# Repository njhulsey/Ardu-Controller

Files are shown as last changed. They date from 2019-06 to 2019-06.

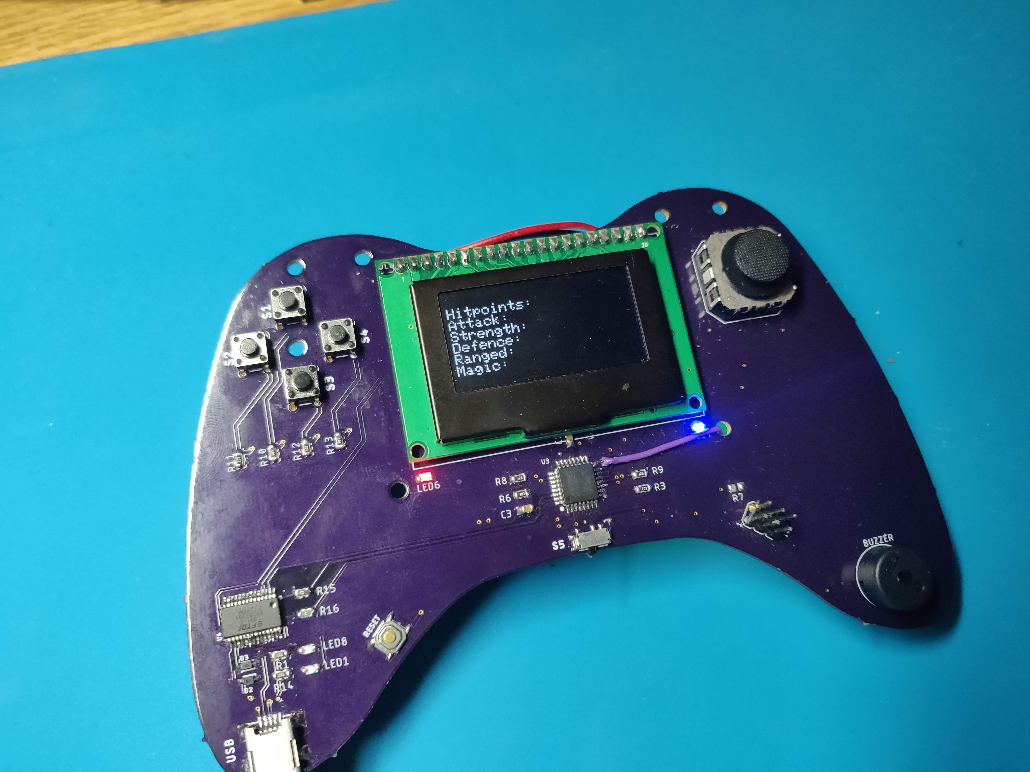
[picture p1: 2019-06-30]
Photo.jpg

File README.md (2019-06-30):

# Ardu-Controller
Arduino inspired hand-held controller!

Contains all of the basic circuitry for an arduino Uno as well as some addition devices:
  - Adafruit OLED
  - Joystick
  - 4 Dip Buttons
  - Buzzer
  - lipo battery charger
  - LEDs
  - Serial (which is used to communicate with a PC)
  
As for the code there are two projects included in this repository. 
The first project is used for controlling a mouse with the game controller using python's serial class.
The second project is snake which can be played on the controller itself.

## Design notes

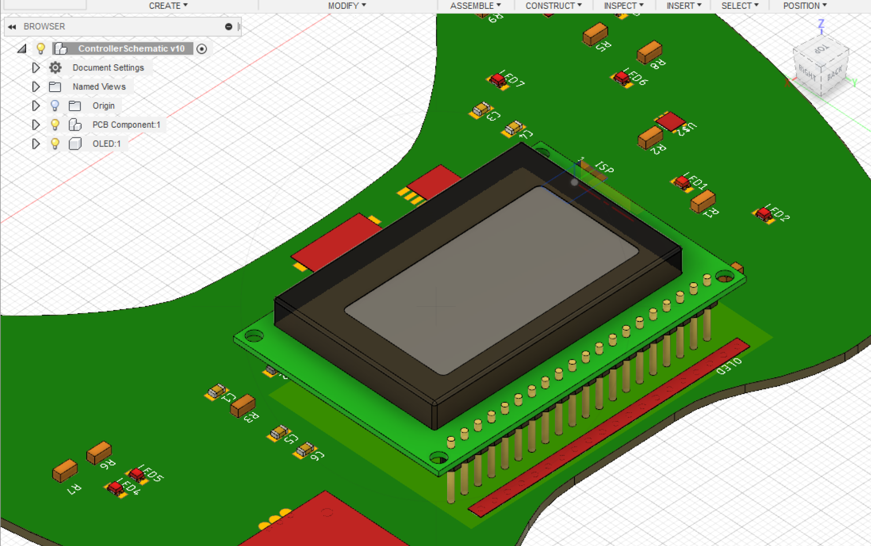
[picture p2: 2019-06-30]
EagleFiles/MechanicalFiles/Sketch.png

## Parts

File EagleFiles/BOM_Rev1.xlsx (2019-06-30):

Part Number | Manufacturer | Description | Reference | Price | Quantity | Link
2765 | Adafruit | Mini 2-Axis Analog Thumbstick |  | $2.50 | 1 | https://www.adafruit.com/product/2765
2720 | Adafruit | Monochrome 1.54" OLED |  | $34.95 | 1 | https://www.adafruit.com/product/2720
97 | Sparkfun | Mini Pushbutton Switch 6mm |  | $0.35 | 1 | https://www.sparkfun.com/products/97
UX60-MB-5ST | Hirose | USB Connector Mini B |  | $0.90 | 1 | https://www.mouser.com/ProductDetail/Hirose-Connector/UX60-MB-5ST
768-1007-1-ND | FTDI | IC USB FS SERIAL UART 28-SSOP |  | $4.50 | 1 | https://www.digikey.com/products/en?keywords=768-1007-1-ND
10860 | Sparkfun | Surface Mount Right Angle Switch |  | $0.95 | 1 | https://www.sparkfun.com/products/10860
1016-1873-1-ND | MaxLinear | IC REG LINEAR 3.3V 500MA SOT23-5 |  | $0.60 | 1 | https://www.digikey.com/product-detail/en/maxlinear-inc/SPX3819M5-L-3-3-TR/1016-1873-1-ND/3586590
MBR120VLSFT3GOSCT | ON Semiconductor | DIODE SCHOTTKY 20V 1A SOD123FL |  | $0.42 | 1 | https://www.digikey.com/product-detail/en/on-semiconductor/MBR120VLSFT3G/MBR120VLSFT3GOSCT-ND/3487322
CDSOD323-T08L | Bourns | ESD 8.5V 1PF SOD323 DIODE |  | $0.76 | 2 | https://www.mouser.com/ProductDetail/Bourns/CDSOD323-T08L
MCP73831T-2ACI/OTCT-ND | Microchip | IC CONTROLLR LI-ION 4.2V SOT23-5 |  | $0.58 | 1 | https://www.digikey.com/product-detail/en/microchip-technology/MCP73831T-2ACI-OT/MCP73831T-2ACI-OTCT-ND/1979802
2011 | Adafruit | LIPO ION BATT - 3.7V 2000mAh |  | $12.50 | 1 | https://www.adafruit.com/product/2011
ATMEGA328P-AU-ND | Microchip | ATMEGA328P 8BIT 32KB FLASH 32TQFP |  | $2.07 | 1 | https://www.digikey.com/product-detail/en/microchip-technology/ATMEGA328P-AU/ATMEGA328P-AU-ND/1832260

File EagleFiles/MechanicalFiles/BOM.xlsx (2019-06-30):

Name | Part Number | ID | Amount | Cost | Link
Atmega328P-PU |  |  |  |  | https://www.digikey.com/product-detail/en/microchip-technology/ATMEGA328P-AU/ATMEGA328P-AU-ND/1832260
Micro USB Connector |  |  |  |  | https://www.alliedelec.com/product/molex-incorporated/54819-0519/70090672/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

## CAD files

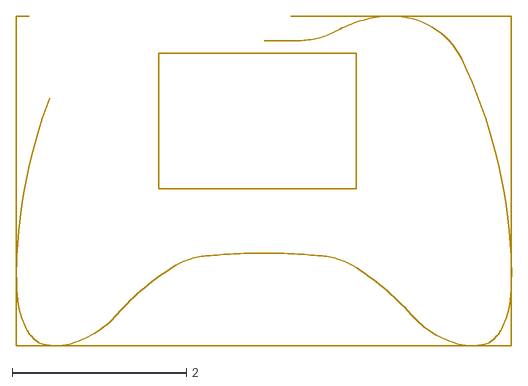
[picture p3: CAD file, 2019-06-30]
EagleFiles/MechanicalFiles/contollerEXPORT.dxf
5.69 x 3.79

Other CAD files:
EagleFiles/MechanicalFiles/ControllerOutline.dwg

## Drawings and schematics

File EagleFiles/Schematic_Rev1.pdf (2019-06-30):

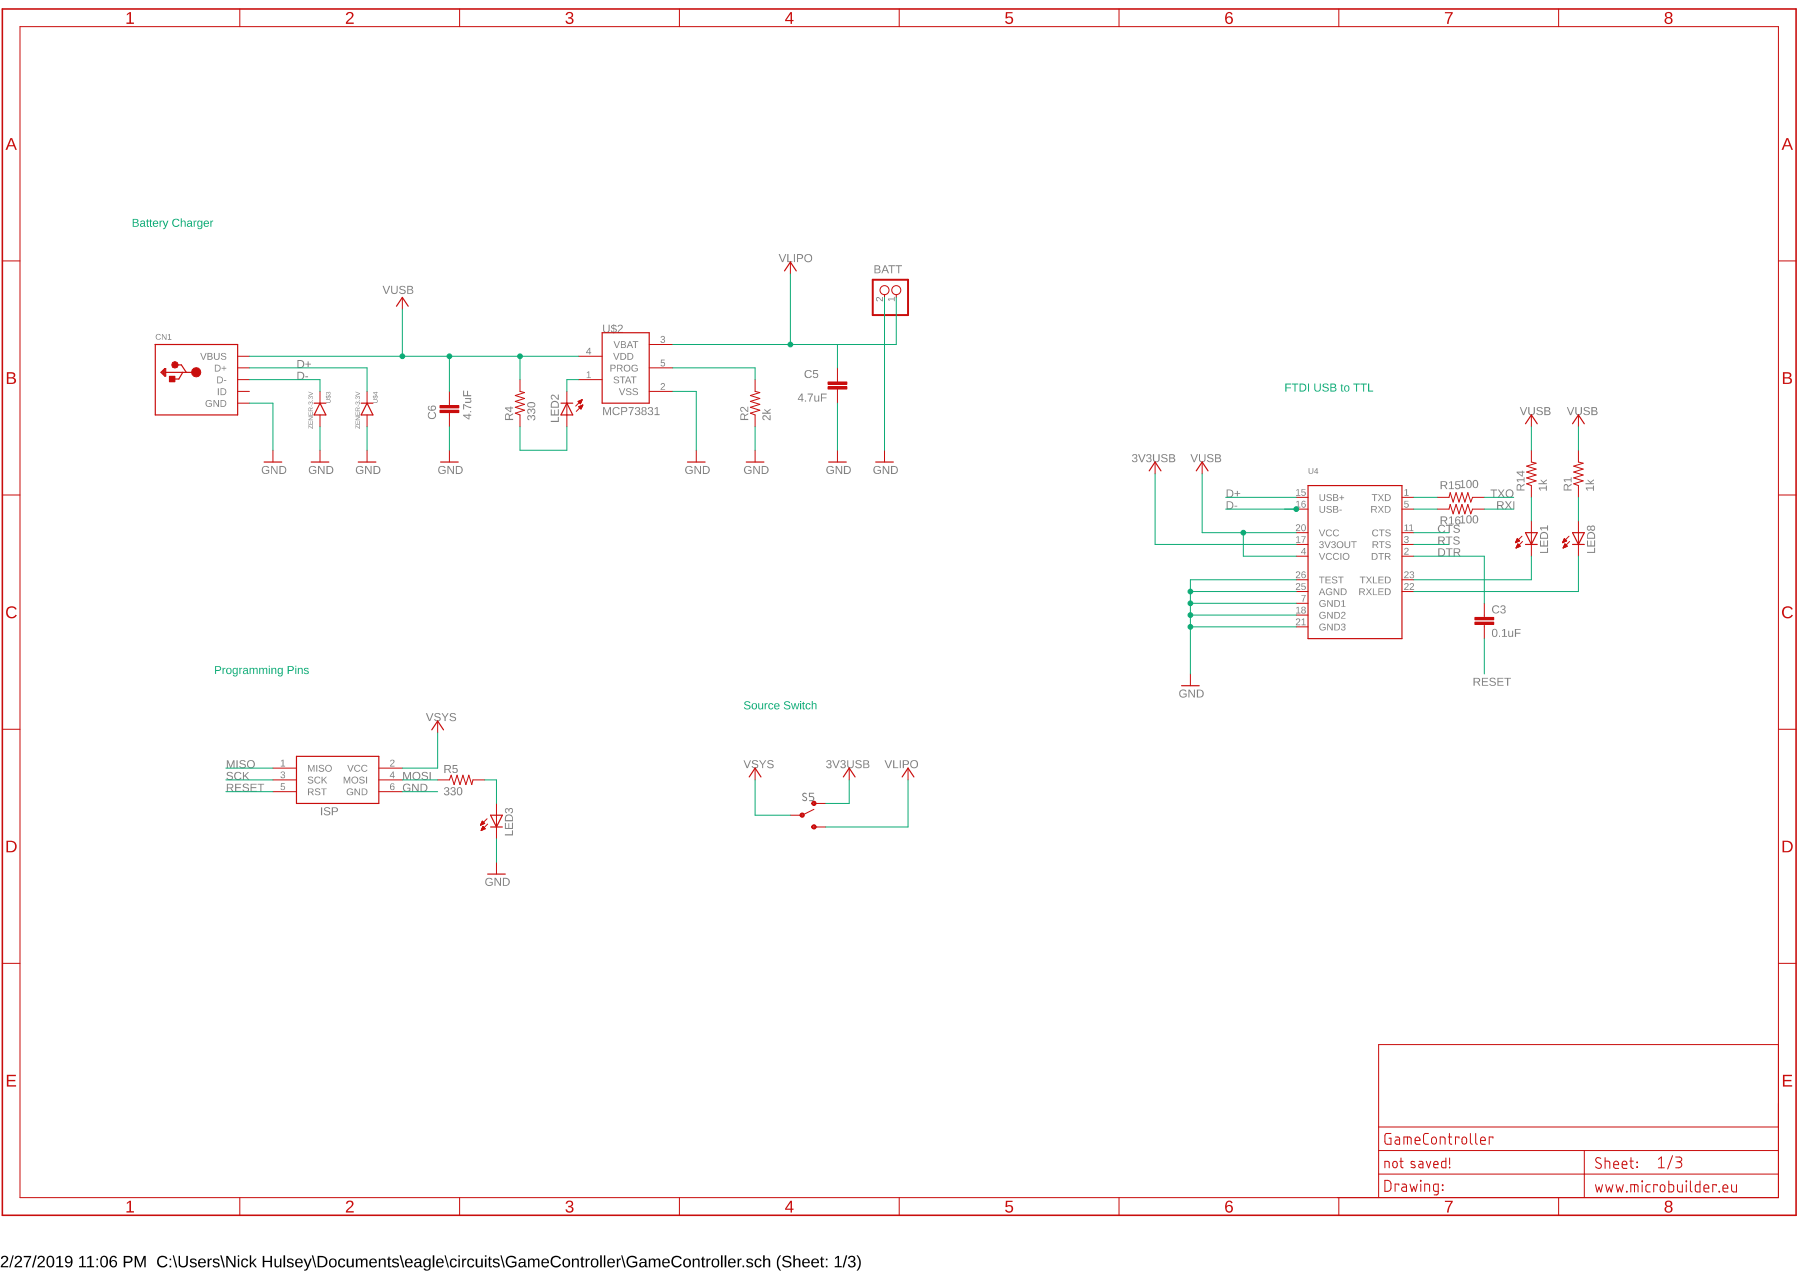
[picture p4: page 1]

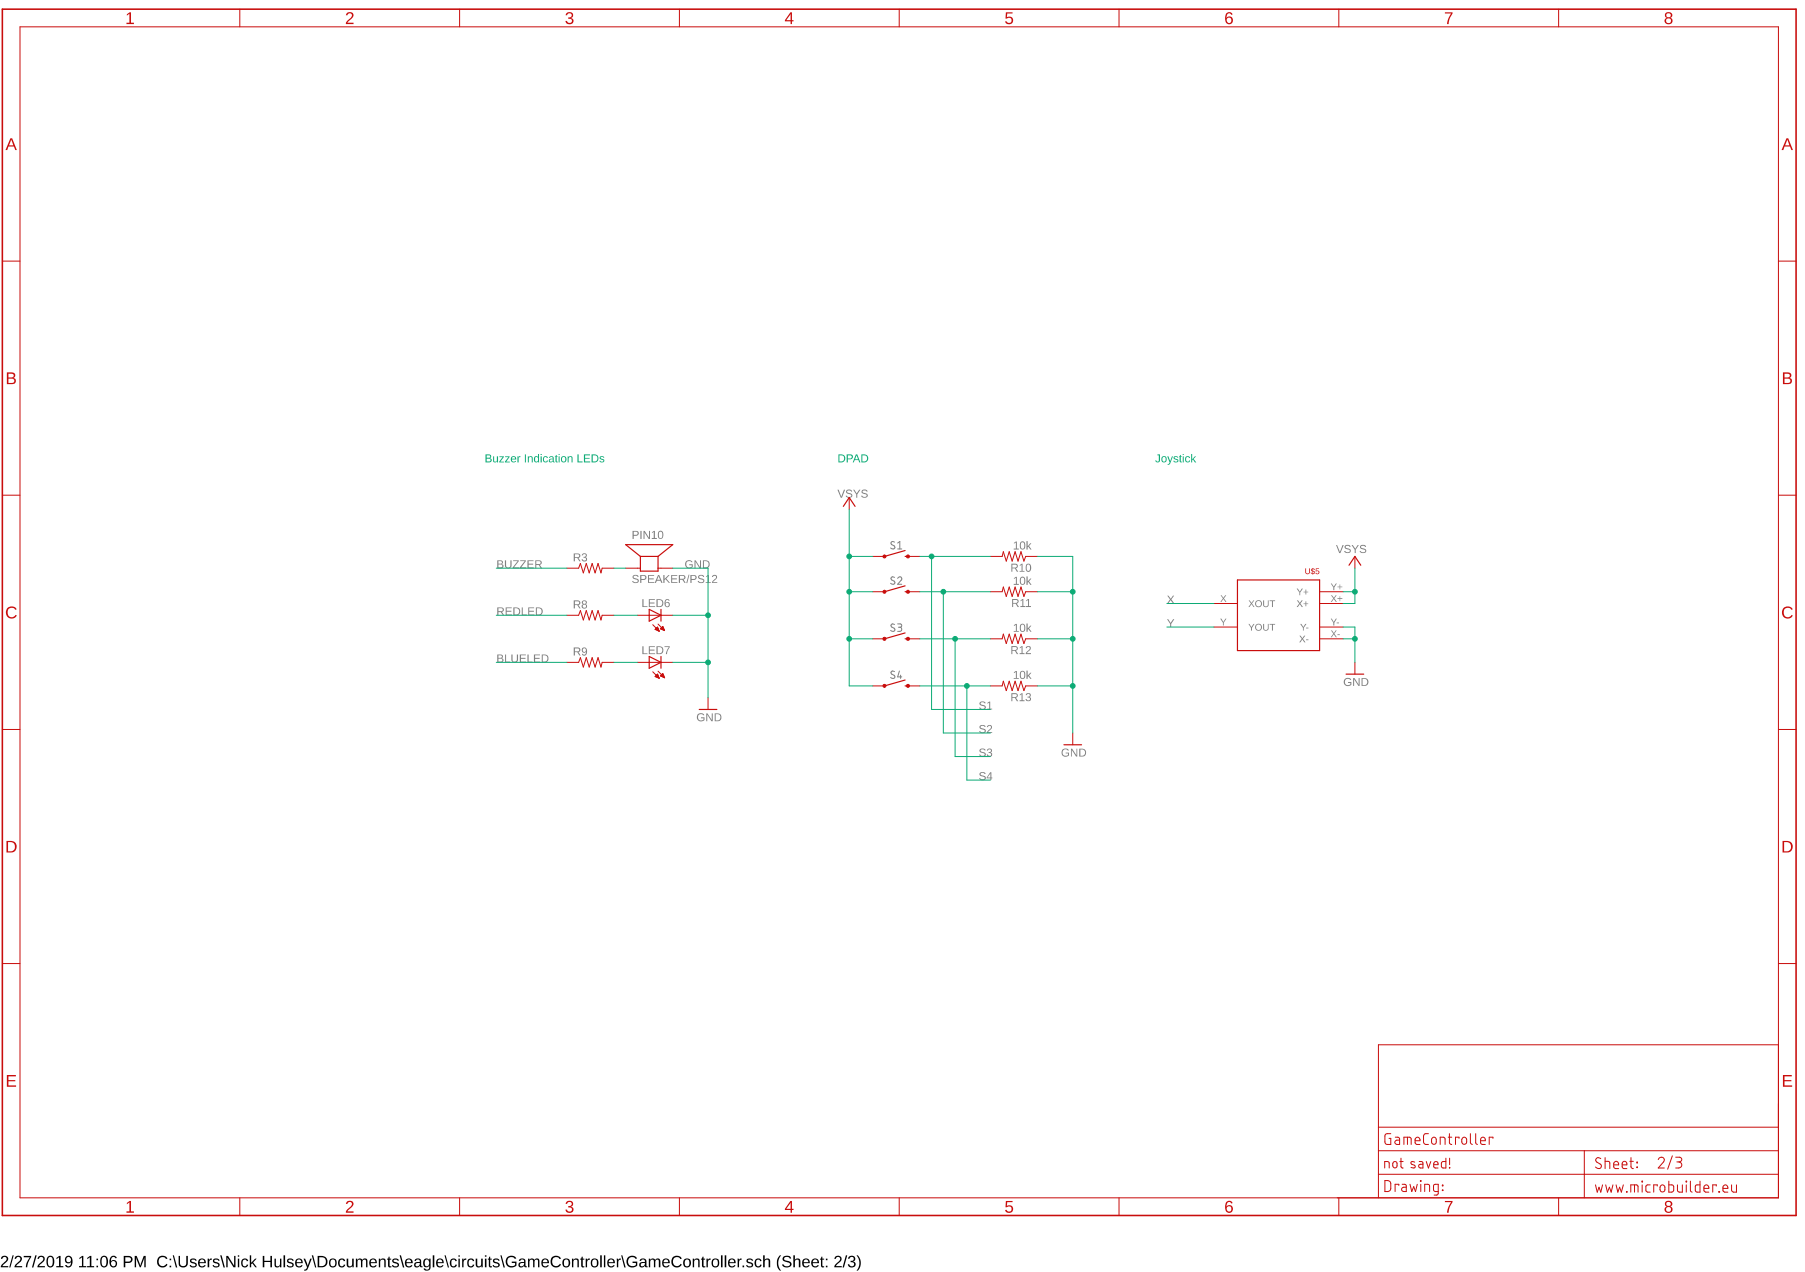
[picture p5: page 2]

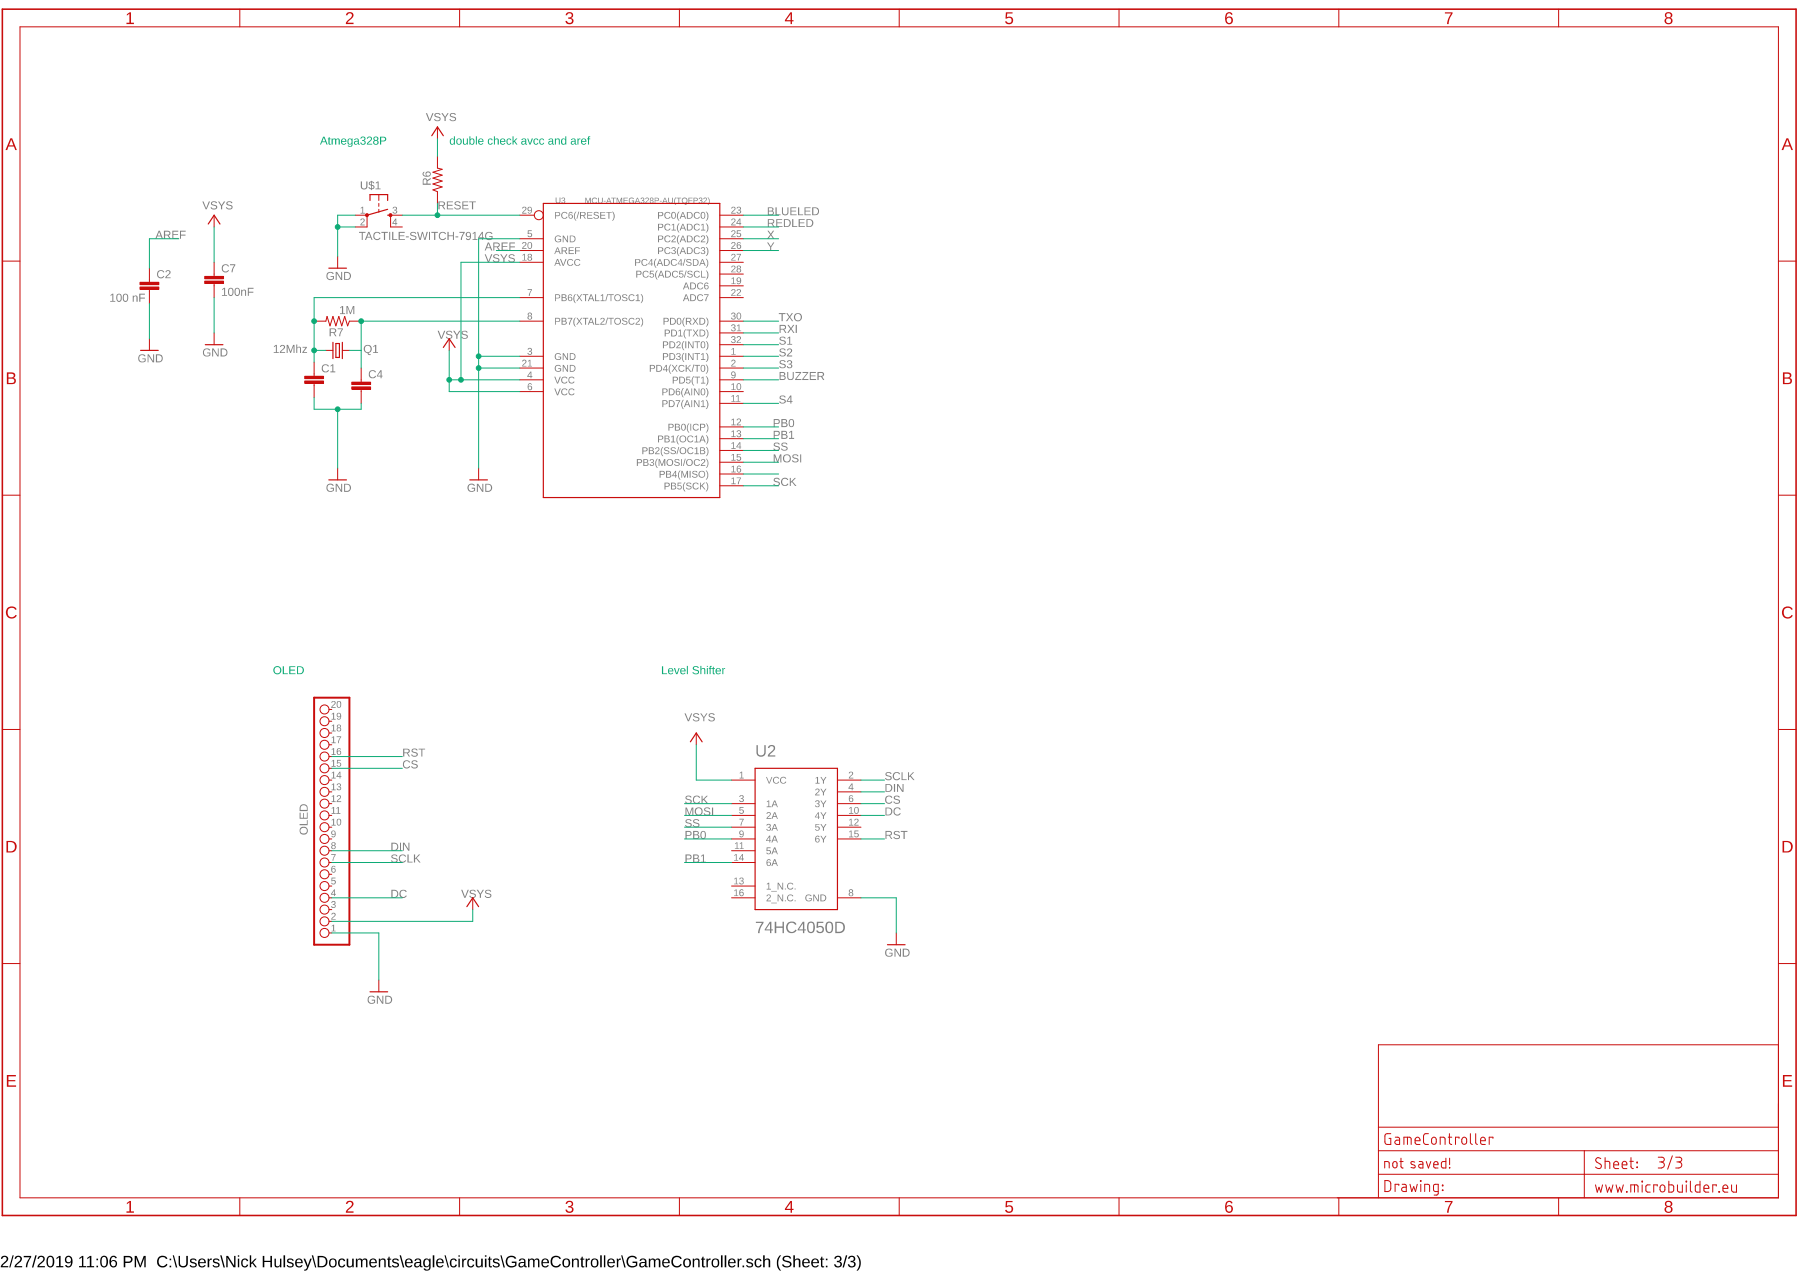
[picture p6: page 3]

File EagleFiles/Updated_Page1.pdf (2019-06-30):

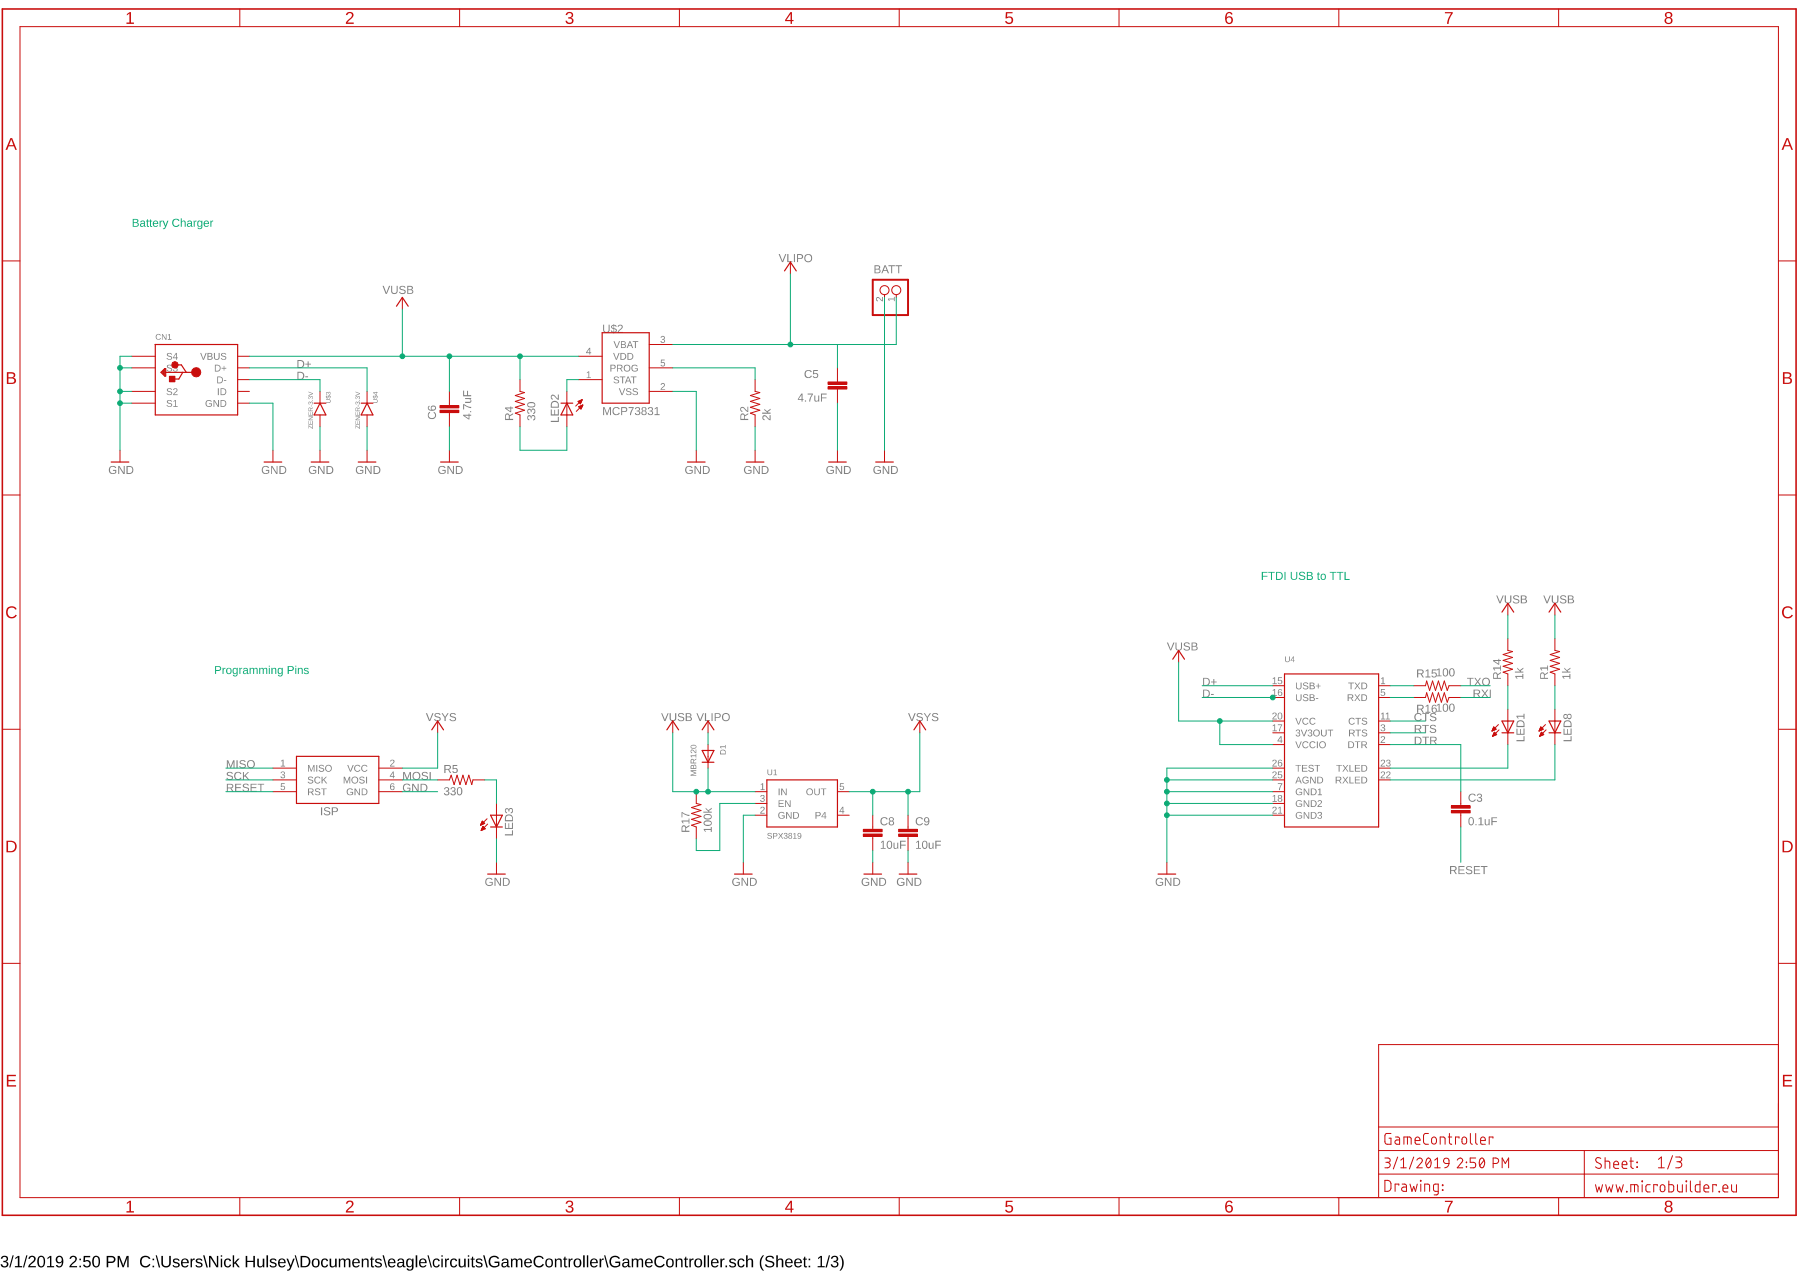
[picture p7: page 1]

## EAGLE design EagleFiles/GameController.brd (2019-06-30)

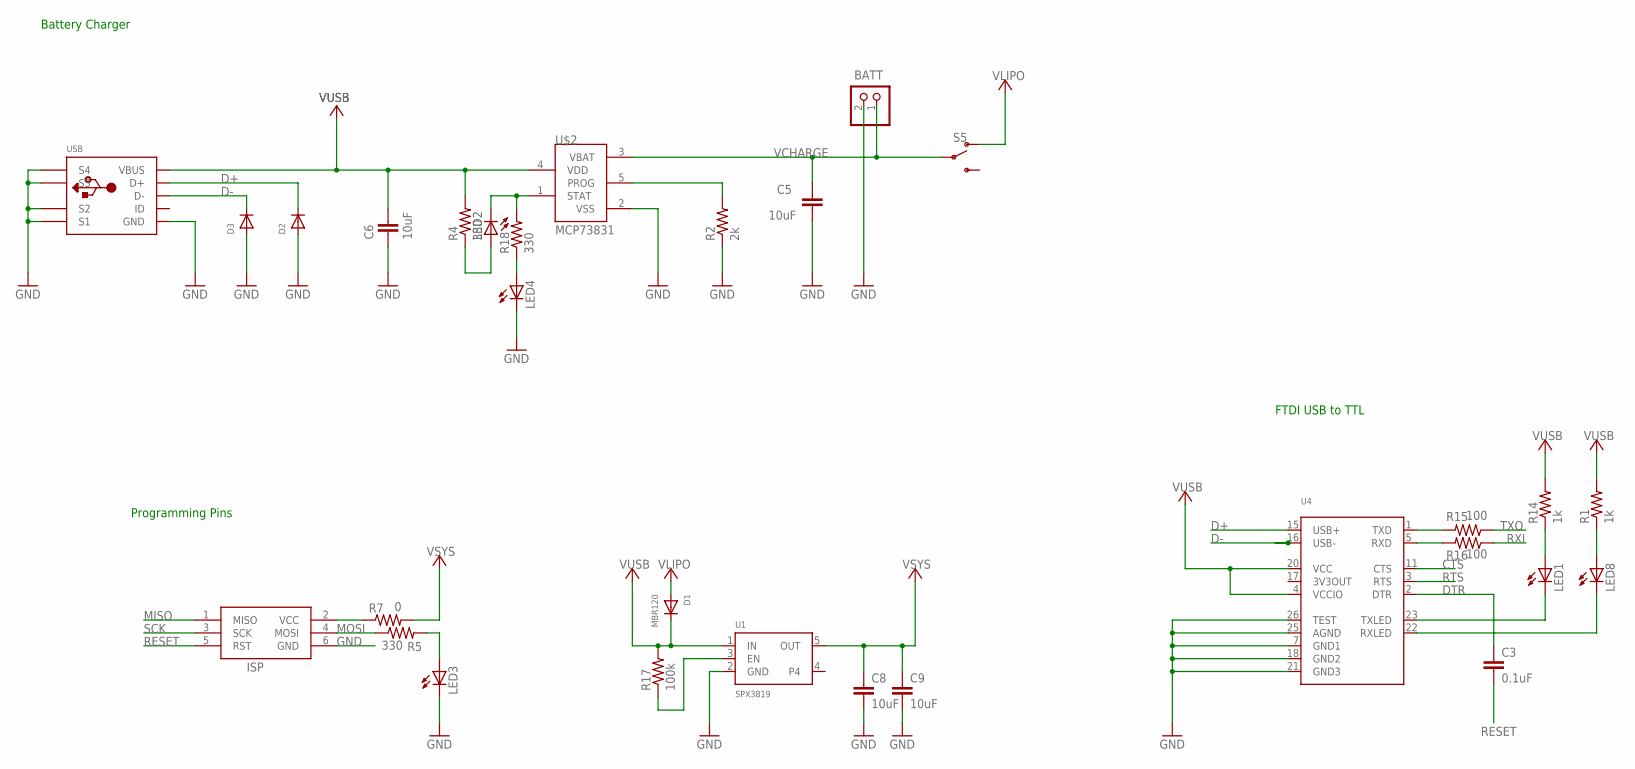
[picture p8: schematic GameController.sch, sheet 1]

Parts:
BATT: JST_2PIN-SMT-RA; JST-PH-2-SMT-RA
C3: 0.1uF; C0805
C5, C6, C8, C9: 10uF; C0805
D1: MBR120; SOD-123
D2, D3: DIODESOD-323; SOD-323
ISP: AVRISP-6; AVRISP
LED1, LED2, LED3, LED4, LED8: LEDCHIPLED_0805; CHIPLED_0805
R1, R14: 1k; R0805
R2: 2k; R0805
R4, R5, R18: 330; R0805
R7: 0; R0805
R15, R16: 100; R0805
R17: 100k; R0805
S5: SWITCH-SPDT-SMD-RIGHT-ANGLE; SWITCH_SPST_SMD_A
U1: SPX3819; SOT23-5
U4: FT232RLSSOP28; SSOP28DB
U$2: MCP73831; SOT23-5L
USB: USBMINIB; USB-MINIB

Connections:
3V3OUT: U4.17 (3V3OUT)
CTS: U4.11 (CTS)
D+: D2.C, U4.15 (USB+), USB.D+
D-: D3.C, U4.16 (USB-), USB.D-
DTR: C3.1, U4.2 (DTR)
GND: BATT.2 (1), C5.2, C6.2, C8.2, C9.2, D2.A, D3.A, ISP.6 (GND), LED3.C, LED4.C, R2.1, U1.2 (GND), U4.7 (GND1), U4.18 (GND2), U4.21 (GND3), U4.25 (AGND), U4.26 (TEST), U$2.2 (VSS), USB.GND, USB.GND1 (S1), USB.GND2 (S2), USB.GND3 (S3), USB.GND4 (S4); also elsewhere on the board
MISO: ISP.1 (MISO); also elsewhere on the board
MOSI: ISP.4 (MOSI), R5.1; also elsewhere on the board
unnamed: LED3.A, R5.2
unnamed: LED2.A, R4.1
unnamed: R15.2, U4.1 (TXD)
unnamed: LED2.C, R18.2, U$2.1 (STAT)
unnamed: R2.2, U$2.5 (PROG)
unnamed: R16.2, U4.5 (RXD)
unnamed: ISP.2 (VCC), R7.1
unnamed: LED4.A, R18.1
unnamed: R17.1, U1.3 (EN)
unnamed: LED1.C, U4.23 (TXLED)
unnamed: LED8.C, U4.22 (RXLED)
unnamed: LED1.A, R14.1
unnamed: LED8.A, R1.1
RESET: C3.2, ISP.5 (RST); also elsewhere on the board
RTS: U4.3 (RTS)
RXI: R16.1; also elsewhere on the board
SCK: ISP.3 (SCK); also elsewhere on the board
TXO: R15.1; also elsewhere on the board
VCHARGE: BATT.1 (2), C5.1, S5.2, U$2.3 (VBAT)
VLIPO: D1.A, S5.1 (O)
VSYS: C8.1, C9.1, R7.2, U1.5 (OUT); also elsewhere on the board
VUSB: C6.1, D1.C, R1.2, R4.2, R14.2, R17.2, U1.1 (IN), U4.4 (VCCIO), U4.20 (VCC), U$2.4 (VDD), USB.VBUS

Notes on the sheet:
Battery Charger
FTDI USB to TTL
Programming Pins

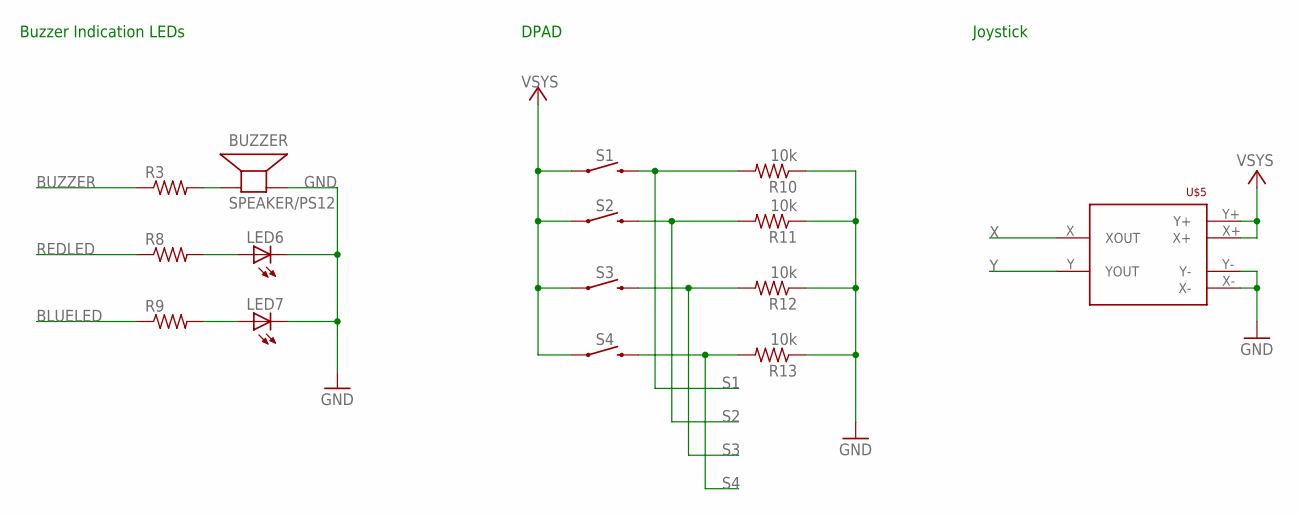
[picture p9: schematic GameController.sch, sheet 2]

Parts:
BUZZER: SPEAKER/PS12; PS12
LED6, LED7: LEDCHIPLED_0805; CHIPLED_0805
R3, R8, R9: R-US_R0805; R0805
R10, R11, R12, R13: 10k; R0805
S1, S2, S3, S4: MOMENTARY-SWITCH-SPST-PTH-6.0MM-KIT; TACTILE_SWITCH_PTH_6.0MM_KIT
U$5: JOYSTICK_ANALOG

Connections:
BLUELED: R9.1; also elsewhere on the board
BUZZER: R3.1; also elsewhere on the board
GND: BUZZER.P$2 (-), LED6.C, LED7.C, R10.1, R11.1, R12.1, R13.1, U$5.X-, U$5.Y-; also elsewhere on the board
unnamed: BUZZER.P$1 (+), R3.2
unnamed: LED6.A, R8.2
unnamed: LED7.A, R9.2
REDLED: R8.1; also elsewhere on the board
S1: R10.2, S1.3 (2); also elsewhere on the board
S2: R11.2, S2.3 (2); also elsewhere on the board
S3: R12.2, S3.3 (2); also elsewhere on the board
S4: R13.2, S4.3 (2); also elsewhere on the board
VSYS: S1.1, S2.1, S3.1, S4.1, U$5.X+, U$5.Y+; also elsewhere on the board
X: U$5.X (XOUT); also elsewhere on the board
Y: U$5.Y (YOUT); also elsewhere on the board

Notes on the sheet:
Buzzer Indication LEDs
DPAD
Joystick

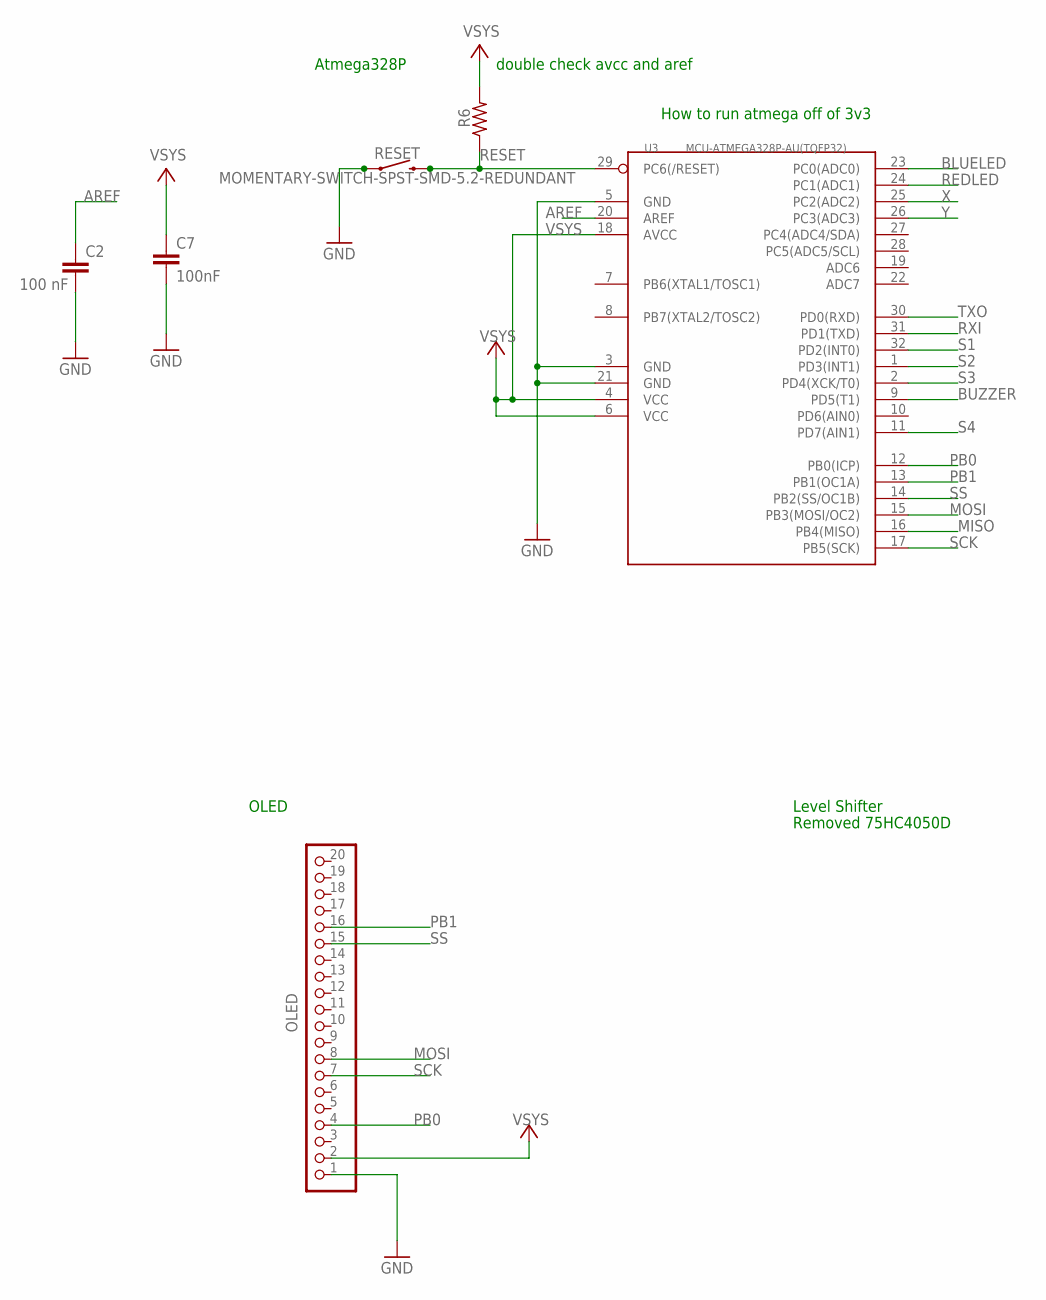
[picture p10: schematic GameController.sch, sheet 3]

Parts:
C2: 100 nF; C0805
C7: 100nF; C0805
OLED: PINHD-1X20-BIG; 1X20-BIG
R6: R-US_R0805; R0805
RESET: MOMENTARY-SWITCH-SPST-SMD-5.2-REDUNDANT; TACTILE_SWITCH_SMD_5.2MM
U3: MCU-ATMEGA328P-AU(TQFP32); TQFP32-0.8-7X7MM

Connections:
AREF: C2.1, U3.20 (AREF)
BLUELED: U3.23 (PC0(ADC0)); also elsewhere on the board
BUZZER: U3.9 (PD5(T1)); also elsewhere on the board
GND: C2.2, C7.2, OLED.1, RESET.1, RESET.2 (1), U3.3 (GND), U3.5 (GND), U3.21 (GND); also elsewhere on the board
MISO: U3.16 (PB4(MISO)); also elsewhere on the board
MOSI: OLED.8, U3.15 (PB3(MOSI/OC2)); also elsewhere on the board
PB0: OLED.4, U3.12 (PB0(ICP))
PB1: OLED.16, U3.13 (PB1(OC1A))
REDLED: U3.24 (PC1(ADC1)); also elsewhere on the board
RESET: R6.1, RESET.3 (2), RESET.4 (2), U3.29 (PC6(/RESET)); also elsewhere on the board
RXI: U3.31 (PD1(TXD)); also elsewhere on the board
S1: U3.32 (PD2(INT0)); also elsewhere on the board
S2: U3.1 (PD3(INT1)); also elsewhere on the board
S3: U3.2 (PD4(XCK/T0)); also elsewhere on the board
S4: U3.11 (PD7(AIN1)); also elsewhere on the board
SCK: OLED.7, U3.17 (PB5(SCK)); also elsewhere on the board
SS: OLED.15, U3.14 (PB2(SS/OC1B))
TXO: U3.30 (PD0(RXD)); also elsewhere on the board
VSYS: C7.1, OLED.2, R6.2, U3.4 (VCC), U3.6 (VCC), U3.18 (AVCC); also elsewhere on the board
X: U3.25 (PC2(ADC2)); also elsewhere on the board
Y: U3.26 (PC3(ADC3)); also elsewhere on the board

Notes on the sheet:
double check avcc and aref
Atmega328P
OLED
Level Shifter
How to run atmega off of 3v3
Removed 75HC4050D

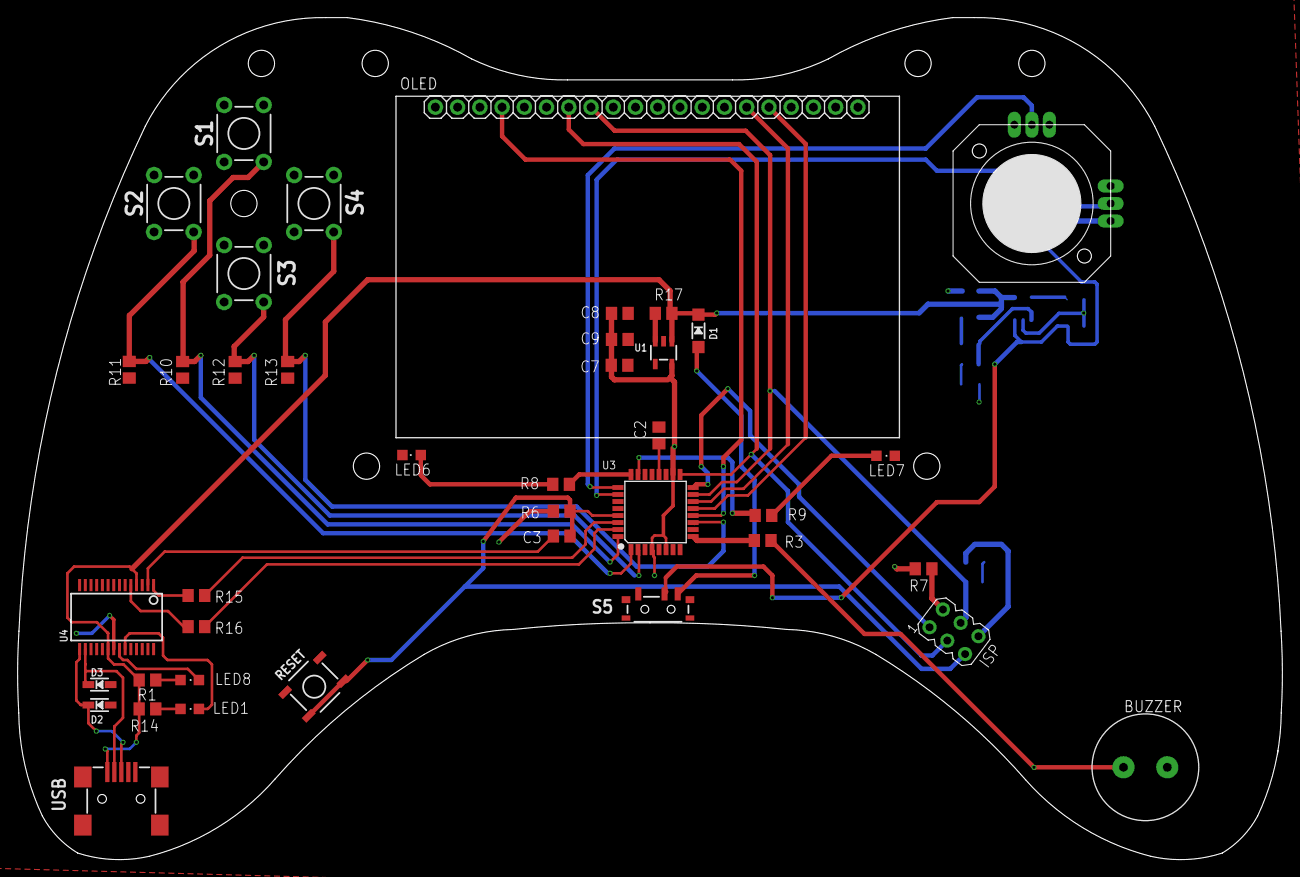
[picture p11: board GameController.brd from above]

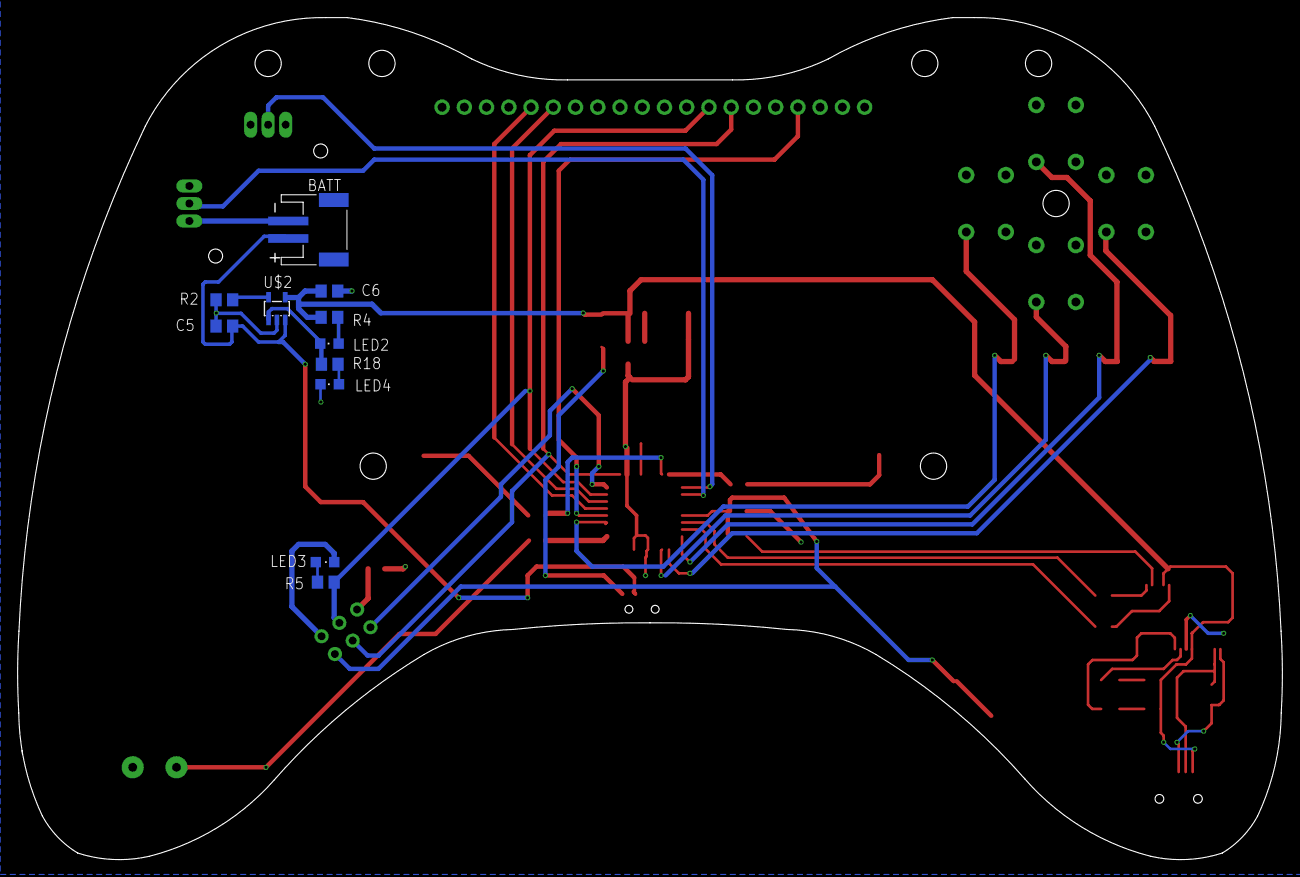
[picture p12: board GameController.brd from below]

Board: 2 copper layers, 144.5 x 96.2 mm, 51 parts (11 on the bottom side), 43 nets.

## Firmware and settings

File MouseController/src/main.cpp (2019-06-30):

#include "Main.h"


Adafruit_SSD1305 display(OLED_DC, OLED_RESET, OLED_CS);

void setup() {
  pinMode(BLUE_LED, OUTPUT);
  pinMode(RED_LED, OUTPUT);

  pinMode(Y_JOYSTICK,INPUT);
  pinMode(X_JOYSTICK,INPUT);

  pinMode(UP_BUTTON,INPUT);
  pinMode(LEFT_BUTTON,INPUT);
  pinMode(DOWN_BUTTON,INPUT);
  pinMode(RIGHT_BUTTON,INPUT);

  pinMode(BUZZER,OUTPUT);

  digitalWrite(RED_LED, HIGH);   // turn the LED on (HIGH is the voltage level)
  digitalWrite(BLUE_LED, HIGH);   // turn the LED on (HIGH is the voltage level)

  display.begin();


  display.display();
  delay(200);
  display.clearDisplay();

  refreshScreen();


  Serial.begin(128000); //9600 19200 115200
  Serial.print("Start Setup:");
}

int pause = 30;
int steps = 50;

int left_last = LOW;
int right_last = LOW;
int down_last = LOW;

int up_button_last = LOW;

String data[8];

String pressW = "";
String pressA = "";
String pressS = "";
String pressD = "";

void loop() {

  int move_tolerance = 350;

  int slow_speed = 4;
  int readY = analogRead(Y_JOYSTICK) - 500;
  int readX = analogRead(X_JOYSTICK) - 500;

  int moveX = (int)((steps/500.0) * readX);
  int moveY = (int)((steps/500.0) * readY);

  //facing left
  if( readX > -1 * move_tolerance && readX < -10){
    moveX = -slow_speed;
  }

  if(readX < move_tolerance && readX > 10){
    moveX = slow_speed;
  }

  if(readY < move_tolerance && readY > 10){
    moveY = slow_speed;
  }

  if(readY > -1 * move_tolerance && readY < -10){
    moveY = -slow_speed;
  }

  if(digitalRead(DOWN_BUTTON) == HIGH){
      //facing left
      if( readX < 0 ){
        moveX = -slow_speed;
      }

      if(readX > 0){
        moveX = slow_speed;
      }

      if(readY > 0){
        moveY = slow_speed;
      }

      if(readY < 0 ){
        moveY = -slow_speed;
      }
  }

  if((readX >= -10 && readX < 0)|| (readX <= 10 && readX > 0))
    moveX = 0;

  if((readY >= -10 && readY < 0) || (readY <= 10 && readY > 0))
    moveY = 0;

  if(digitalRead(UP_BUTTON) == LOW ){
      Serial.print("M:"+String(moveX) + ":" +String(moveY) + ":");
      delay(pause);
  }


  String press = "";
  if(digitalRead(UP_BUTTON) != up_button_last){
    if(digitalRead(UP_BUTTON) == LOW)
      Serial.print("K:W:U:A:U:S:U:D:U:");

    delay(pause);
    up_button_last = digitalRead(UP_BUTTON);
  }


  if(digitalRead(UP_BUTTON) == HIGH){
    int tolerance = 100;
    pressW = "U"; pressS = "U";
    pressA = "U"; pressD = "U";

    if(readX > tolerance) {pressA = "D"; pressD = "U";}
    if(readX < -1 * tolerance) {pressD = "D"; pressA = "U";}
    if(readY > tolerance) {pressW = "U"; pressS = "D";}
    if(readY < -1 * tolerance) {pressS = "U"; pressW = "D";}


    Serial.print("K:W:" + pressW + ":A:" + pressA + ":S:" + pressS + ":D:" + pressD + ":");
    delay(pause);
  }

  //Left click
  if (digitalRead(RIGHT_BUTTON) == HIGH && right_last == LOW) {
    Serial.print("B:R:");
    delay(pause);
  }
  right_last = digitalRead(RIGHT_BUTTON);


  //Right Click
  if (digitalRead(LEFT_BUTTON) == HIGH && left_last == LOW) {
    Serial.print("B:L:");
    delay(pause);
  }
  left_last = digitalRead(LEFT_BUTTON);




  if(Serial.available() > 0){
    String raw = Serial.readStringUntil(':');
    int index = raw.charAt(0) - '0';
    String text = raw.substring(1);
    data[index] = text;
    refreshScreen();
  }

  if(digitalRead(DOWN_BUTTON) == HIGH && down_last == LOW){
    Serial.print("B:D:");
    delay(pause);
  }
  down_last = digitalRead(DOWN_BUTTON);




}

void refreshScreen(){
  display.clearDisplay();
  display.setTextSize(1);
  display.setTextWrap(false);
  display.setTextColor(WHITE);
  display.setCursor(0,0);

  display.println(data[0]);
  display.println("Hitpoints:" + data[1]);
  display.println("Attack:" + data[2]);
  display.println("Strength:" + data[3]);
  display.println("Defence:" + data[4]);
  display.println("Ranged:" + data[5]);
  display.println("Magic:" + data[6]);
  display.display();
}

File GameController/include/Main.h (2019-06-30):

#ifndef __Main_H__
#define __Main_H__

#include <Wire.h>
#include <SPI.h>
#include "Arduino.h"


/*
#include <Adafruit_GFX.h>
#include <Adafruit_SSD1305.h>
*/
//#include "Game.h"

// Used for software or hardware SPI
// Used for software SPI
#define OLED_CLK 13
#define OLED_MOSI 11

// Used for software or hardware SPI
#define OLED_CS 10
#define OLED_DC 8

// Used for I2C or SPI
#define OLED_RESET 9

#define SCREEN_WIDTH 128
#define SCREEN_HEIGHT 64

#define BLUE_LED 14
#define RED_LED 15

#define Y_JOYSTICK A2
#define X_JOYSTICK A3

#define UP_BUTTON 2
#define LEFT_BUTTON 3
#define DOWN_BUTTON 4
#define RIGHT_BUTTON 7

#define BUZZER 5

//extern Adafruit_SSD1305 display(OLED_DC, OLED_RESET, OLED_CS);

#endif

void setup();
void loop();

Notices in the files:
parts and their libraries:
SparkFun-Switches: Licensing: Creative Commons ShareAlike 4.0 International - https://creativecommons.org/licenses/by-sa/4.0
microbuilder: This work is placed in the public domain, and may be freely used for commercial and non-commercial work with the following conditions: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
